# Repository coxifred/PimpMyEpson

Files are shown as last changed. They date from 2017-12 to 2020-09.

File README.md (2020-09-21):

### **Welcome to the PimpMyEpson!**

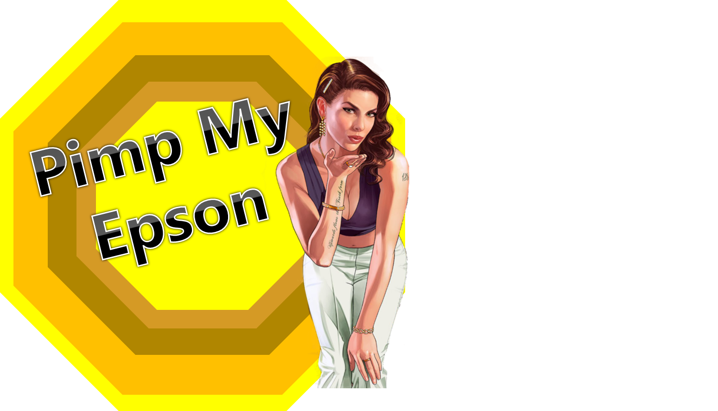
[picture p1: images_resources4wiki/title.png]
PimpMyEpson


## **Quick description**

The purpose is to build a mini wifi projector control module with a simple Wemos R1 mini (ESP8266) Module.

_All starts with a virtual overview:_

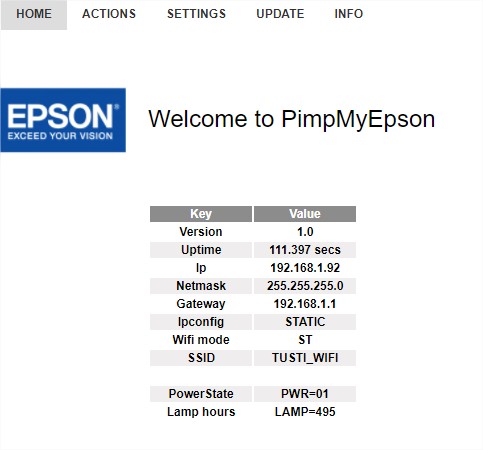
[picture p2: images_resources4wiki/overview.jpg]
virtualOverview


## **Features**

_Here are the indispensables features i have implemented:_

**1.Control EPSON projector from wifi and get informations (like Lamp hour).

**2.Customs commands based on Epson documentation [Here](https://github.com/coxifred/PimpMyEpson/blob/master/ESCVP21_e_P.pdf)

**3.Json feedback.

**4.Custom network configuration (wifi,static dhcp..)

**5.Updateable on the air.

## **Installation**

Just plug the box in the RS232 of your projector and bring USB power to the box.

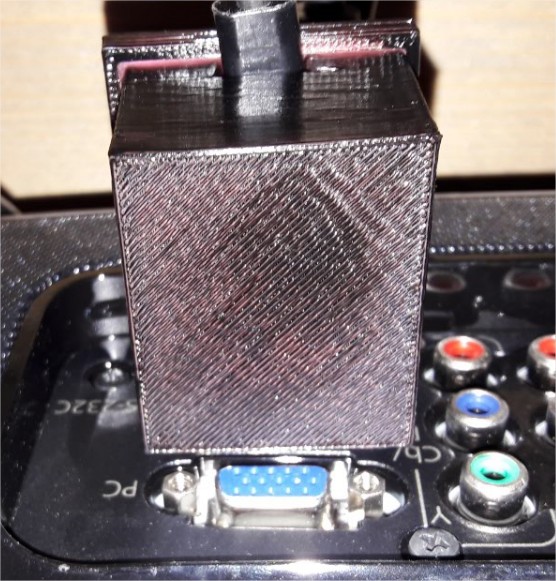
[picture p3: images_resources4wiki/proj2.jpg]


## **Configuration**

Very simple, at the first start, PimpMyEpson will provide a Wifi hotspot (Normally PimpMyEpson_***).
Connect to the device with a wifi phone or tablet.

You could choose in network menu wifi mode (Station or AccessPoint), and dhcp or static ip adress.

Wifi profile (Station or AccessPoint)

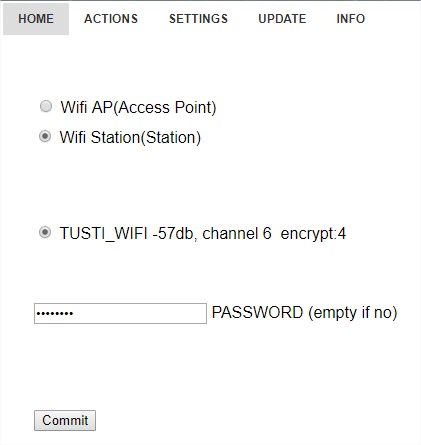
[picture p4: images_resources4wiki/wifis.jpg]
wifi


Network profile (Static or DHCP)

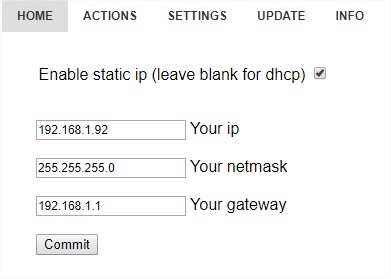
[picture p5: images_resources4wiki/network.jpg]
network


## **Hardware**

Less than 10euros, found on known electronics websites.

ESP Wemos Mini D1 mini
RS232 interface

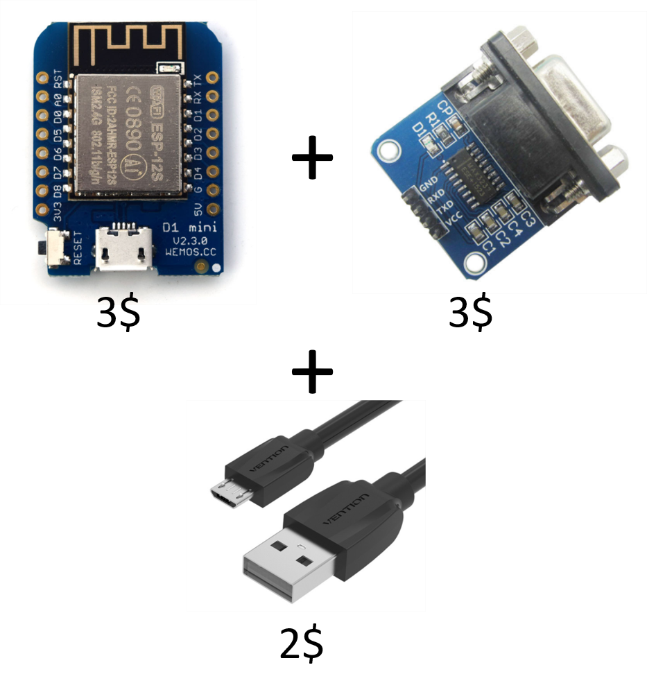
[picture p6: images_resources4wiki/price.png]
price


Box printed :

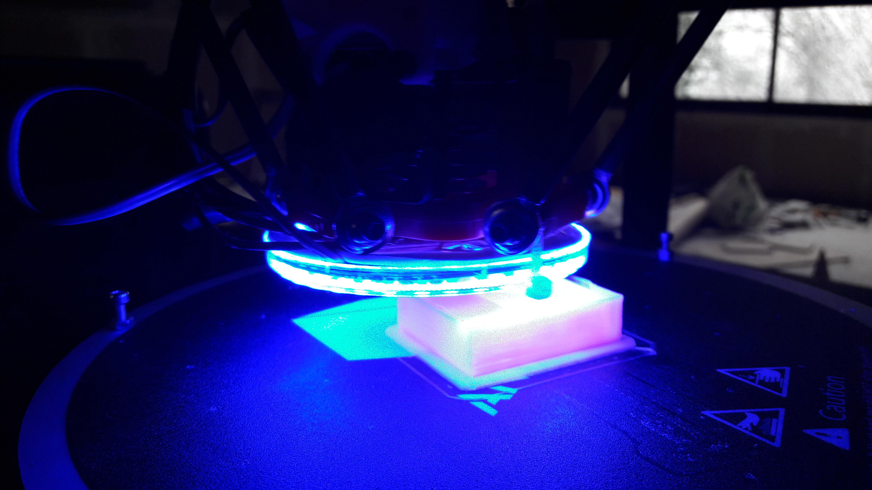
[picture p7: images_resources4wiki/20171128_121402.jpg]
printed


[STL render box](https://github.com/coxifred/PimpMyEpson/blob/master/3d/PimpMyEpsonBoite.stl).

[STL render cover](https://github.com/coxifred/PimpMyEpson/blob/master/3d/PimpMyEpsonCouvercle.stl).

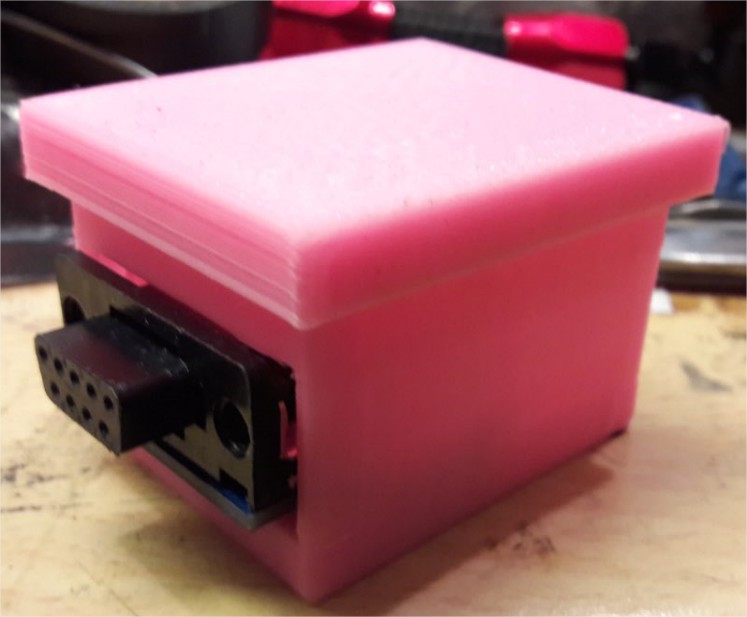
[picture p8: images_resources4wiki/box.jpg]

<br>
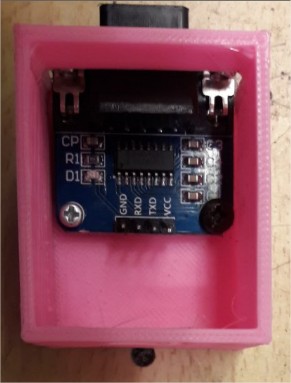
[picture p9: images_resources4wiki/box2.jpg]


This box has been printed and built with openScad, an excellent 3D software designer [OPENScad](http://www.openscad.org/).
No more click, you design your model with code, 3DAC (3D as code) :) (so easy to adjust).

Click [here](https://github.com/coxifred/PimpMyEpson/blob/master/3d/PimpMyEpson.scad) to download the openScad box file, as you see, very simple :

```
/**
Boite pour PimpMyEpson avec openScad
2017 (Fred)
**/

// La boite principale
module boite()

{   

     // Intersection trapeze USB et boite

    difference() {
        // Intersection trapeze RS232 et boite
        difference() {
            // Intersection des 2 boites
            difference() {
                translate([-18,0,0]) cube ([36,44,27]);
                translate([-16,1,2]) cube ([32,41,25]);
            }
            translate([0,5,18])  rotate([90,180,0]) linear_extrude (height=10) polygon (points=[[-9,0],[9,0],[7,8],[-7,8]]);
        }
       translate([0,45,20])  rotate([90,0,0])  linear_extrude (height=10)  polygon (points=[[-5,0],[5,0],[4,4],[-4,4]]);
    }
}

// Le couvercle
module couvercle()
{
  // Intersection avec le couvercle
  rotate([180,0,0]) translate([45,-44,-29]) difference() {
                       // Couvercle
                       translate([-18,0,25]) cube ([36,44,4]);   
                       boite();
                       }
}

// La marche interne
module marche();
{
  // La marche interne
  translate([-16,36,2]) rotate([90,0,90]) linear_extrude (height=32) polygon (points=[[-4,0],[6,0],[6,10],[-2,10]]);  
}

boite();
couvercle();
marche();
```

## **Software**

You can find sources [here](https://github.com/coxifred/PimpMyEpson/tree/master/sources)

You can find image  [here](https://github.com/coxifred/PimpMyEpson/tree/master/bin) (just upload to your wemos with arduino IDE or other flashtool)

## **Utilisation**

Some actions :

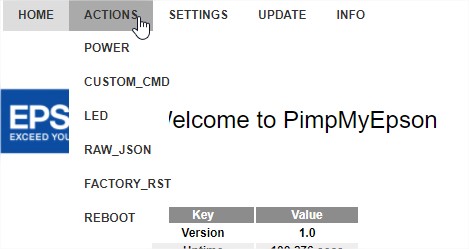
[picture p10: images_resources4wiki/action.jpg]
actions


Custom command screen:

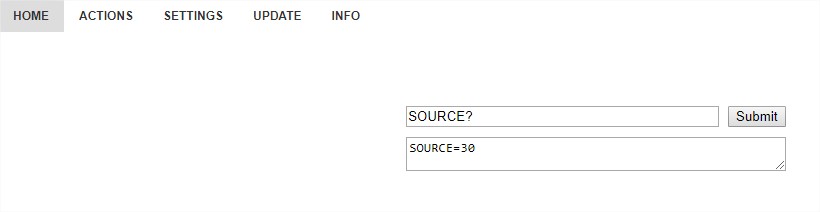
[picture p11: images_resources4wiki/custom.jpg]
custom


Json raw:

// 20171204223950
// http://<module_ip>/json

{
  "version": "1.0",
  "starttime": 358453,
  "ip": "192.168.1.92",
  "netmask": "255.255.255.0",
  "gateway": "192.168.1.1",
  "wifimode": "ST",
  "ipconfig": "STATIC",
  "ssid": "TUSTI_WIFI",
  "password": "****",
  "lampeHours": "LAMP=495",
  "powerState": "PWR=01"
}

Api for custom command:

Just use http://<module_ip>/command?cmd=<your_espon_command> in response, the videoprojector answer.

## **Wiring**
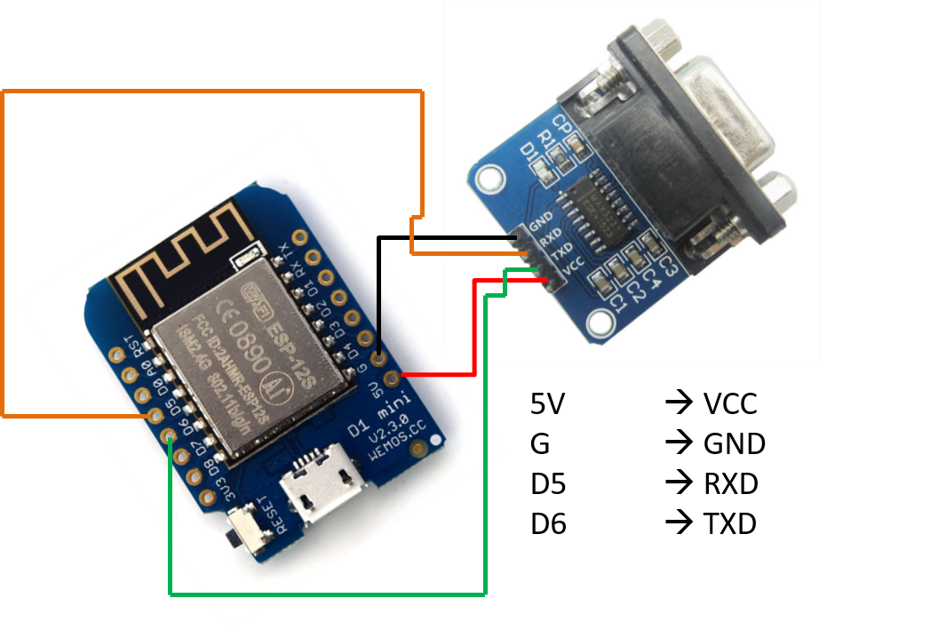
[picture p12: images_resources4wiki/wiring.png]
wiring


## **Shots of reality (Proto #0)**

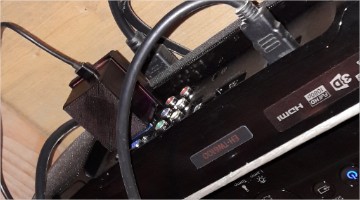
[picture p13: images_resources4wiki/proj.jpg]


Some Gorilla's HomeAutomate integration:

After plugin Espon added:

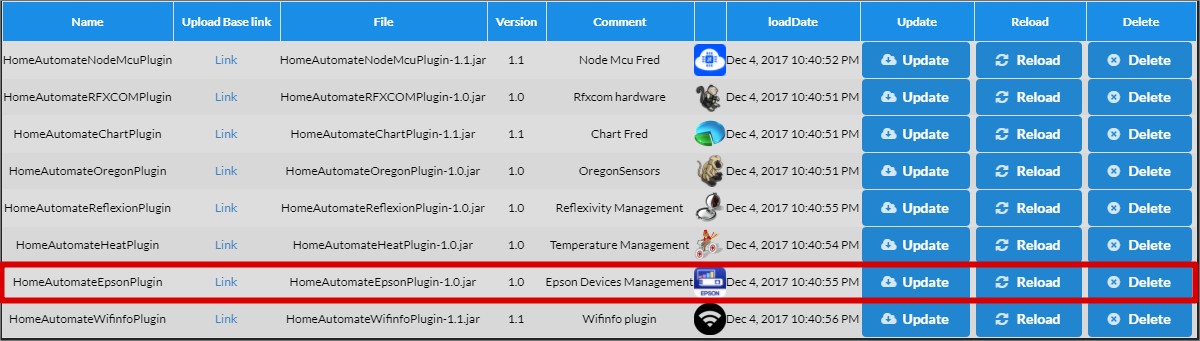
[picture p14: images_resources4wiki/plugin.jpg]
plugin


Insert widget:

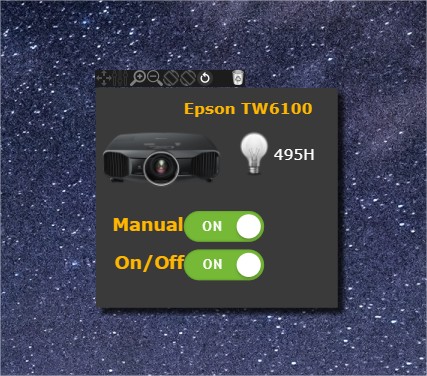
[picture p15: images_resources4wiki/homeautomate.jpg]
homeautomate


OUn Oun !

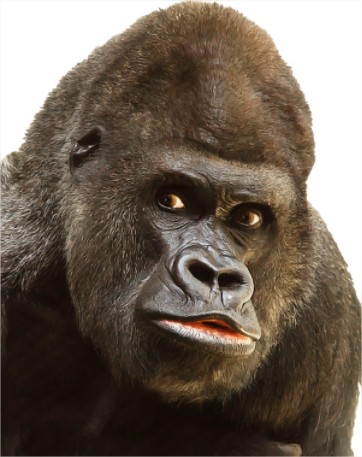
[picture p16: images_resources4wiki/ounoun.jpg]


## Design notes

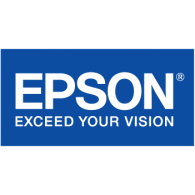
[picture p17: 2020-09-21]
sources/epson.png

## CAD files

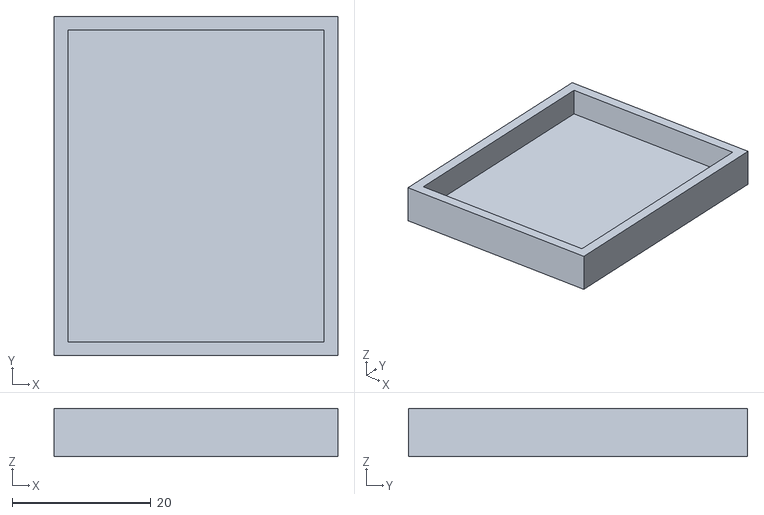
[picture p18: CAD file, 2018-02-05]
3d/PimpMyEpsonCouvercle.stl
41.0 x 49.0 x 7.00

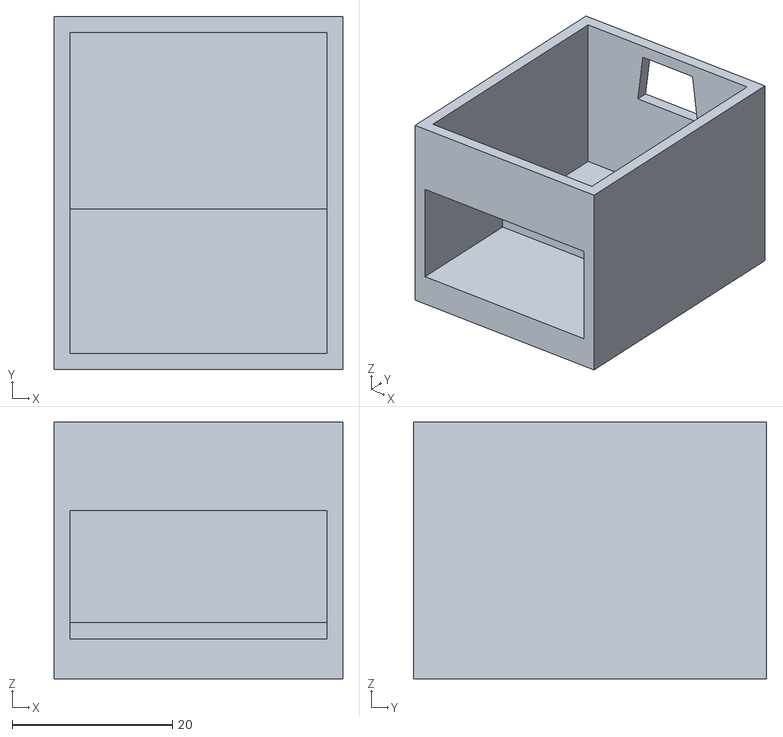
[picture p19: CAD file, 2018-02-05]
3d/PimpMyEpsonBoite.stl
36.0 x 44.0 x 32.0

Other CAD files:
3d/PimpMyEpson.scad

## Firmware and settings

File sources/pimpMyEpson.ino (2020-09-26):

/**
 * PimpMyEpson (2017)
 * Gorille70, tusti70@gmail.com
 * 
 * Drive your Epson projector by wifi
 * 
 * Changes :
 * 26/09/2020 : Avoid wifi reset to factory, if wifi ssid is not here, fix communication issue (parasites)
 */

#include <ESP8266WiFi.h>
#include <WiFiClient.h>
#include <ESP8266WebServer.h>
#include <SoftwareSerial.h>
#include <Chrono.h>
#include <pgmspace.h>
#include <ESP8266mDNS.h>


#include "MemoryWebResources.h"
#include "EEPROMAnything.h"
#define PSTR(s) (__extension__({static const char __c[] PROGMEM = (s); &__c[0];}))
#define FPSTR(pstr_pointer) (reinterpret_cast<const __FlashStringHelper *>(pstr_pointer))
#define F(string_literal) (FPSTR(PSTR(string_literal)))


// Data structure
typedef struct {
  char anIP[20];
  char aNetmask[20];
  char aGateway[20];
  char aWifiMode[20];
  char aIpConfig[20];
  char ssid[20];
  char password[20];
  uint16_t crc;
} Configuration __attribute__ ((packed));

// The configuration object
Configuration pimpConfig;

// Wemos mapping <-> arduino for help
//static const uint8_t D0   = 16;
//static const uint8_t D1   = 5;
//static const uint8_t D2   = 4;
//static const uint8_t D3   = 0;
//static const uint8_t D4   = 2;
//static const uint8_t D5   = 14;
//static const uint8_t D6   = 12;
//static const uint8_t D7   = 13;
//static const uint8_t D8   = 15;
//static const uint8_t RX   = 3;
//static const uint8_t TX   = 1;

// Serial definition for EPSON protocol 
// Don't use RX/TX
//static const uint8_t RX   = 3;
//static const uint8_t TX   = 1;
SoftwareSerial mySerial(D5, D6); //2 is TX, 14 is RX, corresponding to D5 and D6 on wemos

// Ip Adress Object
IPAddress ip;
// The Web server
ESP8266WebServer server(80);

// Some values
String ledValue="off";
String version="2.0";
String host="PimpMyEpson";
String jsonScanWifi="";
int ledState = LOW;
int wifiFailure=0;

// A Chronograph 
Chrono myChrono;
unsigned long previousMillis = 0;
unsigned long previousMillisWifi = 0;
unsigned long previousMillisReboot = 0;
const long interval = 1000;
const long intervalWifi = 180000;
const long intervalReboot = 1000 * 60 * 60 * 1;

// Main Setup
void setup(void){
  myChrono.restart();
  Serial.begin(115200);
  Serial.println("Setting port for EPSON protocol speed 9600...");
  mySerial.begin(9600);
  Serial.println("Reading Parameters...");
  readParameters();
  Serial.println("Booting PimpMyEpson...");
  setupWifi();
  pinMode(LED_BUILTIN, OUTPUT); // Initialize the LED_BUILTIN pin as an output
  pinMode(A0, INPUT);
}


// Method for setting WIFI (Access Point or Station)
void setupWifi()
{
  scanWifi();
  Serial.println(" - Setting up wifi...");
  if ( strcmp(pimpConfig.aWifiMode, "AP")  == 0) 
  {
    Serial.println("    * Set access point mode");
    setAPWifi();
  }else
  {
    Serial.println("    * Set station mode");
    setStationWifi();
  }
}

// Reset config, to factory settings
void resetConfig()
{
  Serial.println("Reset SSID");
  sprintf_P(pimpConfig.ssid, "PimpMyEpson-%06X", ESP.getChipId());
  //strcpy_P(pimpConfig.ssid, "PimpMyEpson" + );
  Serial.println("Reset anIP");
  strcpy_P(pimpConfig.anIP, "192.168.1.1");
  Serial.println("Reset aNetmask");
  strcpy_P(pimpConfig.aNetmask, "255.255.255.0");
  Serial.println("Reset aGateway");
  strcpy_P(pimpConfig.aGateway, "192.168.1.254");
  Serial.println("Reset aWifiMode");
  strcpy_P(pimpConfig.aWifiMode, "AP");
  Serial.println("Reset aIpConfig");
  strcpy_P(pimpConfig.aIpConfig,"STATIC");
  Serial.println("Reset password");
  strcpy_P(pimpConfig.password, "");
}

// Read Parameters
void readParameters()
{
   EEPROM.begin(1024);
   if (readConfig(false)) {
    Serial.println("Good configuration");
   }else
   {
    Serial.println("Bad configuration, restore factory settings");
    memset(&pimpConfig, 0, sizeof(Configuration));
    resetConfig();
    saveConfig();
   }
   showConfig();
}

// Display configuration to COM PORT
void showConfig() 
{
  Serial.println("***** Wifi"); 
  Serial.print("ssid     : "); Serial.println(pimpConfig.ssid); 
  Serial.print("passwd   : "); Serial.println(pimpConfig.password); 
  Serial.print("wifiMode : "); Serial.println(pimpConfig.aWifiMode); 
  Serial.println("\r\n****** Network"); 
  Serial.print("ip       : "); Serial.println(pimpConfig.anIP); 
  Serial.print("netmask  : "); Serial.println(pimpConfig.aNetmask); 
  Serial.print("gateway  : "); Serial.println(pimpConfig.aGateway); 
  Serial.print("ipconfig : "); Serial.println(pimpConfig.aIpConfig); 
  Serial.println("");
}

// Save configuration
bool saveConfig (void) 
{
  Serial.println("Saving Configuration");
  uint8_t * pconfig ;
  bool ret_code;
  pconfig = (uint8_t *) &pimpConfig ;
  pimpConfig.crc = ~0;
  for (uint16_t i = 0; i < sizeof (Configuration) - 2; ++i)
    pimpConfig.crc = crc16Update(pimpConfig.crc, *pconfig++);
  pconfig = (uint8_t *) &pimpConfig ;
  for (uint16_t i = 0; i < sizeof(Configuration); ++i) 
  EEPROM.write(i, *pconfig++);
  EEPROM.commit();
  ret_code = readConfig(false);
  Serial.print(F("Write the configuration "));
  if (ret_code)
    Serial.println(F("OK!"));
  else
    Serial.println(F("Error!"));
  return (ret_code);
}

// Read Configuration 
bool readConfig (bool clear_on_error) 
{
  uint16_t crc = ~0;
  uint8_t * pconfig = (uint8_t *) &pimpConfig ;
  uint8_t data ;
  for (uint16_t i = 0; i < sizeof(Configuration); ++i) {
    data = EEPROM.read(i);
    *pconfig++ = data ;
    crc = crc16Update(crc, data);
  }
  if (crc != 0) {
    if (clear_on_error)
      memset(&pimpConfig, 0, sizeof( Configuration ));
    return false;
  }
  return true ;
}

// Update CRC
uint16_t crc16Update(uint16_t crc, uint8_t a)
{
  int i;
  crc ^= a;
  for (i = 0; i < 8; ++i)  {
    if (crc & 1)
      crc = (crc >> 1) ^ 0xA001;
    else
      crc = (crc >> 1);
  }
  return crc;
}




// Led Request processing, allow on, off and blinking
void processLed()
  {
        ledValue=server.arg("state");
        if (ledValue == "on") digitalWrite(LED_BUILTIN, LOW);
        else if (ledValue == "off") digitalWrite(LED_BUILTIN, HIGH);
        server.send(200, "text/plain", "Led is now " + ledValue);
        Serial.print("Led is now ");
        Serial.println(ledValue);
  }


// Kowned informations process, returns as JSON format
void processInformations()
  {
        long elapsed = myChrono.elapsed();
        String json="{";
        json=json +"\"version\":\"" + version +"\",";
        json=json +"\"starttime\":" + elapsed + ",";
        json=json +"\"ip\":\"" + ipToString(WiFi.localIP()) + "\",";
        json=json +"\"netmask\":\"" + pimpConfig.aNetmask + "\",";
        json=json +"\"gateway\":\"" + pimpConfig.aGateway + "\",";
        json=json +"\"wifimode\":\"" + pimpConfig.aWifiMode + "\",";
        json=json +"\"ipconfig\":\"" + pimpConfig.aIpConfig + "\",";
        json=json +"\"ssid\":\"" + pimpConfig.ssid + "\",";
        json=json +"\"password\":\"" + pimpConfig.password + "\",";
        json=json +"\"lampeHours\":\"" + sendCommand("LAMP?") + "\",";
        json=json +"\"powerState\":\"" + sendCommand("PWR?") + "\"";
        json=json +"}";
        server.send(200, "text/plain", json);
  }

// Set mode to access point wifi
void setAPWifi()
{
  
  Serial.println("    * Setting wifi access point starting by reseting factory settings");
  resetConfig();
  strcpy_P(pimpConfig.aWifiMode, "AP");
  if ( strcmp(pimpConfig.password, "") != 0 )
  {
    WiFi.softAP((const char*)pimpConfig.ssid,(const char*)pimpConfig.password);  
  }else
  {
    WiFi.softAP((const char*)pimpConfig.ssid);
  }
  
  int A_IP=atoi(subStr(pimpConfig.anIP, ".", 1));int B_IP=atoi(subStr(pimpConfig.anIP, ".", 2));int C_IP=atoi(subStr(pimpConfig.anIP, ".", 3));int D_IP=atoi(subStr(pimpConfig.anIP, ".", 4));
  int A_GW=atoi(subStr(pimpConfig.aGateway, ".", 1));int B_GW=atoi(subStr(pimpConfig.aGateway, ".", 2));int C_GW=atoi(subStr(pimpConfig.aGateway, ".", 3));int D_GW=atoi(subStr(pimpConfig.aGateway, ".", 4));
  int A_SN=atoi(subStr(pimpConfig.aNetmask, ".", 1));int B_SN=atoi(subStr(pimpConfig.aNetmask, ".", 2));int C_SN=atoi(subStr(pimpConfig.aNetmask, ".", 3));int D_SN=atoi(subStr(pimpConfig.aNetmask, ".", 4));

  IPAddress ip(A_IP, B_IP, C_IP, D_IP);
  IPAddress gateway(A_GW, B_GW, C_GW, D_GW);
  IPAddress subnet(A_SN, B_SN, C_SN, D_SN);
  WiFi.softAPConfig(ip, gateway, subnet);
  ip=WiFi.softAPIP();
  manageServerHttp();
  Serial.print("    * Ready in AP Wifi mode with SSID: [");
  Serial.print(pimpConfig.ssid);
  Serial.print("] password: [");
  Serial.print(pimpConfig.password);Serial.println("]");
  Serial.print(" - Open http://");
  Serial.print(ip);
  Serial.println(" in your favorite browser");
  server.send(200, "text/plain", ipToString(ip));
}

// Set mode to Station wifi
void setStationWifi()
{
 Serial.println("    * Setting wifi station");
 strcpy_P(pimpConfig.aWifiMode, "ST");
 showConfig();
 WiFi.mode(WIFI_STA);
 if ( strcmp(pimpConfig.password, "") != 0 )
 WiFi.begin((const char*)pimpConfig.ssid, (const char*)pimpConfig.password);

 if ( strcmp(pimpConfig.aIpConfig, "STATIC") == 0 )
 {
  int A_IP=atoi(subStr(pimpConfig.anIP, ".", 1));int B_IP=atoi(subStr(pimpConfig.anIP, ".", 2));int C_IP=atoi(subStr(pimpConfig.anIP, ".", 3));int D_IP=atoi(subStr(pimpConfig.anIP, ".", 4));
  int A_GW=atoi(subStr(pimpConfig.aGateway, ".", 1));int B_GW=atoi(subStr(pimpConfig.aGateway, ".", 2));int C_GW=atoi(subStr(pimpConfig.aGateway, ".", 3));int D_GW=atoi(subStr(pimpConfig.aGateway, ".", 4));
  int A_SN=atoi(subStr(pimpConfig.aNetmask, ".", 1));int B_SN=atoi(subStr(pimpConfig.aNetmask, ".", 2));int C_SN=atoi(subStr(pimpConfig.aNetmask, ".", 3));int D_SN=atoi(subStr(pimpConfig.aNetmask, ".", 4));
 
  IPAddress ip(A_IP, B_IP, C_IP, D_IP);
  IPAddress gateway(A_GW, B_GW, C_GW, D_GW);
  IPAddress subnet(A_SN, B_SN, C_SN, D_SN);
 
  WiFi.config(ip, gateway, subnet);
 }
 
 uint8_t timeout = 600; 
 Serial.print("    * Waiting connection aknowledge .");    
 while ( WiFi.waitForConnectResult() != WL_CONNECTED && timeout )
   {
    Serial.print(".");
    delay(500);
    --timeout;
   }
 Serial.println(".");
 if ( timeout <= 0)
 {
  Serial.println("Wifi connection failed, check ssid and password, reseting to access point");
  server.send(200, "text/plain", "KO");
 }else
 {
 
  MDNS.begin((const char*)host.c_str());
  manageServerHttp();
  MDNS.addService("http", "tcp", 80);
  ip=WiFi.localIP();
  Serial.print("    * Ready in Station Wifi mode with SSID: [");
  strcpy_P(pimpConfig.aNetmask,ipToString(WiFi.subnetMask()).c_str());
  strcpy_P(pimpConfig.aGateway,ipToString(WiFi.gatewayIP()).c_str());
  
  Serial.print(pimpConfig.ssid);
  Serial.print("] password: [");
  Serial.print(pimpConfig.password);Serial.println("]");
  Serial.print(" - Open http://");
  Serial.print(ip);
  saveConfig();
  Serial.println(" in your favorite browser");
  server.send(200, "text/plain", ipToString(ip));
  
 }
   
}

/**
 * Return a String from an IpObject
 */
String ipToString(IPAddress ip){
  String s="";
  for (int i=0; i<4; i++)
    s += i  ? "." + String(ip[i]) : String(ip[i]);
  return s;
}


// HTTP Server request Management
void manageServerHttp()
{
    // Head HTTP Management
    server.on("/", HTTP_GET, [](){
      //server.sendHeader("Connection", "close");
      //server.setContentLength(strlen_P(DATA_index));
      //server.sendHeader("Cache-Control", "max-age=290304000, public");
      //server.sendHeader("Access-Control-Allow-Origin", "*");
      server.sendHeader("content-encoding","gzip");
      //server.sendContent_P( DATA_index, sizeof(DATA_index) );
      server.send_P(200,"text/html",DATA_index,sizeof(DATA_index));
    });
    
    // When Epson Logo is requested
    server.on ("/logo.png", HTTP_GET, [](){
      server.setContentLength(strlen_P(DATA_logo));
      server.sendHeader("Cache-Control", "max-age=290304000, public");
      server.sendContent_P( DATA_logo, sizeof(DATA_logo) );
    });

    // Clean reboot request
    server.on("/reboot", HTTP_GET, [](){
      Serial.println("Reboot asked..");
      ESP.restart();
    });

    // Led management request
    server.on("/led", [](){
      processLed();
    });

    // Display knowned informations
    server.on("/info", [](){
      processInformations();
    });
    
    // Display knowned informations JSON
    server.on("/json", [](){
      processInformations();
    });

    // Reset factory settings
    server.on("/factory", [](){
      resetConfig();
      saveConfig();
      showConfig();
    });

    server.on("/scanWifi", [](){
      server.send(200, "text/plain", scanWifi());
    });
    
    // Wifi Access point management 
    server.on("/wifiAp", [](){
      strcpy_P(pimpConfig.ssid, server.arg("ssid").c_str());
      strcpy_P(pimpConfig.password, server.arg("passwd").c_str());
      strcpy_P(pimpConfig.aIpConfig, server.arg("ipconfig").c_str());
      setAPWifi();
    });

    // Wifi Station management
    server.on("/wifiStation",[](){
      strcpy_P(pimpConfig.ssid, server.arg("ssid").c_str());
      strcpy_P(pimpConfig.password, server.arg("passwd").c_str());
      strcpy_P(pimpConfig.aIpConfig, server.arg("ipconfig").c_str());
      setStationWifi();
    });

    // Command to videoprojector
     server.on("/command",[](){
      String aFeedback=sendCommand(server.arg("cmd"));
      server.send(200, "text/plain", aFeedback);
    });

    // Command poweroff
    server.on("/poweroff",[](){
      String aFeedback=sendCommand("PWR OFF");
      server.send(200, "text/plain", aFeedback);
    });
    
    // Command poweron
    server.on("/poweron",[](){
      String aFeedback=sendCommand("PWR ON");
      server.send(200, "text/plain", aFeedback);
    });
    
    // Network management (staticIP)
    server.on("/staticIp", [](){
      strcpy_P(pimpConfig.aGateway, server.arg("gateway").c_str());
      strcpy_P(pimpConfig.aNetmask, server.arg("netmask").c_str());
      strcpy_P(pimpConfig.anIP, server.arg("ip").c_str());
      strcpy_P(pimpConfig.aIpConfig, "STATIC");
      saveConfig();
      showConfig();
      Serial.println("Rebooting");
      ESP.restart();
    });

     // Network management (dhcpIP)
    server.on("/dhcpIp", [](){
      strcpy_P(pimpConfig.aGateway, "");
      strcpy_P(pimpConfig.aNetmask, "");
      strcpy_P(pimpConfig.anIP, "");
      strcpy_P(pimpConfig.aIpConfig, "DHCP");
      saveConfig();
      showConfig();
      Serial.println("Rebooting");
      ESP.restart();
    });


    // On update request, with upload file
    server.on("/update", HTTP_POST, [](){
      server.sendHeader("Connection", "close");
      server.sendHeader("Access-Control-Allow-Origin", "*");
      server.send(200, "text/plain", (Update.hasError())?"FAIL":"OK");
      ESP.restart();
    },[](){
      HTTPUpload& upload = server.upload();
      if(upload.status == UPLOAD_FILE_START){
        Serial.setDebugOutput(true);
        WiFiUDP::stopAll();
        Serial.printf("Update: %s\n", upload.filename.c_str());
        uint32_t maxSketchSpace = (ESP.getFreeSketchSpace() - 0x1000) & 0xFFFFF000;
        if(!Update.begin(maxSketchSpace)){//start with max available size
          Update.printError(Serial);
        }
      } else if(upload.status == UPLOAD_FILE_WRITE){
        if(Update.write(upload.buf, upload.currentSize) != upload.currentSize){
          Update.printError(Serial);
        }
      } else if(upload.status == UPLOAD_FILE_END){
        if(Update.end(true)){ //true to set the size to the current progress
          Serial.printf("Update Success: %u\nRebooting...\n", upload.totalSize);
        } else {
          Update.printError(Serial);
        }
        Serial.setDebugOutput(false);
      }
      yield();
    });

    // Starting webServer
    server.begin();
}

/**
 * Method for scanning wifi network SSID
 */
String scanWifi()
{
  Serial.println(" - Scanning wifi...");
  int Tnetwork = WiFi.scanNetworks();
  Serial.printf("    * %d network(s) found\n", Tnetwork);
  jsonScanWifi="{\"wifiNetworks\":[";
  for (int i = 0; i < Tnetwork; i++)
  {
    jsonScanWifi=jsonScanWifi + "{";
    jsonScanWifi=jsonScanWifi + "\"index\":" + (i+1) + ",";
    jsonScanWifi=jsonScanWifi + "\"name\":\"" + WiFi.SSID(i).c_str() + "\",";
    jsonScanWifi=jsonScanWifi + "\"channel\":" + WiFi.channel(i) + ",";
    jsonScanWifi=jsonScanWifi + "\"rssi\":" + WiFi.RSSI(i) + ",";
    jsonScanWifi=jsonScanWifi + "\"encrypt\":" + WiFi.encryptionType(i) + ",";
    jsonScanWifi=jsonScanWifi + "},";
  }
  jsonScanWifi=jsonScanWifi +"]}";
  jsonScanWifi.replace(",}","}");
  jsonScanWifi.replace(",]","]");
  Serial.println("    * " + jsonScanWifi);
  return jsonScanWifi;
}

/**
 * Main Loop 
 */
void loop(void){
  server.handleClient();
  delay(1);
  unsigned long currentMillis = millis();
  unsigned long currentMillisWifi = millis();
  unsigned long currentMillisReboot = millis();
  if(currentMillis - previousMillis >= interval && ledValue == "blink" ) {
        previousMillis = currentMillis;
        if (ledState == LOW)
        {
          ledState = HIGH;  // Note that this switches the LED *off*
        }
        else
        {
          ledState = LOW;   // Note that this switches the LED *on*
        }
        digitalWrite(LED_BUILTIN, ledState);
   }
   if(currentMillisWifi - previousMillisWifi >= intervalWifi ) {
        previousMillisWifi = currentMillisWifi;
        
        // Wifi Test, still there ? mode Station only
       if ( strcmp(pimpConfig.aWifiMode, "ST")  == 0) 
        {
          Serial.println("    * Heartbeat (every minute) Checking wifi status, when mode station selected");
          if ( WiFi.waitForConnectResult() )
          {
            Serial.println("    * Heartbeat (every minute) Wifi station Ok, nothing to do.");  
          }else
          {
            Serial.println("    * Heartbeat (every minute) Wifi station seems to be bad, reconnect...");
            setStationWifi();
          }
        }
     }
    if(currentMillisReboot - previousMillisReboot >= intervalReboot ) {
        previousMillisReboot = currentMillisReboot;
        Serial.println("   Reboot now, intervalReboot reached");
        ESP.restart();
     }
  

}

/**
 * Send command for videoprojector via Serial
 */
String sendCommand(String command)
{
  Serial.println("    * Flushing serial");
  mySerial.flush();
  Serial.println("    * Sending command " + command );
  mySerial.println(command);
  delay(50);
  if (mySerial.available()>0)
  {
     String feedback=mySerial.readString();
     // Remove carriage return;
     feedback.replace("\n:","");
     feedback.replace("\r:","");
     mySerial.flush();
     return feedback;
  }
  //while(mySerial.available()>0) {
  //   String feedback=mySerial.readString();
  //   // Remove carriage return;
  //   feedback.replace("\n:","");
  //   feedback.replace("\r:","");
  //   Serial.println("    * Feedback to command " + command + " => " + feedback);
  //   Serial.println("    * Flushing serial");
  //   mySerial.flush();
  //   return feedback;
  // }
   Serial.println("    * No Feedback to command " + command + " :(");
   Serial.println("    * Flushing serial");
   mySerial.flush();
   return "no_response";
}

/**
 * Allow a substring from a String
 */
char* subStr (char* input_string, char *separator, int segment_number) {
 char *act, *sub, *ptr;
 static char copy[20];
 int i;
 strcpy(copy, input_string);
 for (i = 1, act = copy; i <= segment_number; i++, act = NULL) {
  sub = strtok_r(act, separator, &ptr);
  if (sub == NULL) break;
 }
 return sub;
}

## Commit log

2017-12-03 Add scad
    [PimpMyEpson.scad]
2020-09-26 Update pimpMyEpson.ino
    Avoid wifi reset to factory, if wifi ssid is not here, fix communication issue (parasites)
    [pimpMyEpson.ino]
